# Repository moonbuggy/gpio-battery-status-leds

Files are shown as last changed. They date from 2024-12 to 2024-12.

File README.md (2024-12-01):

# GPIO Battery Status LEDs
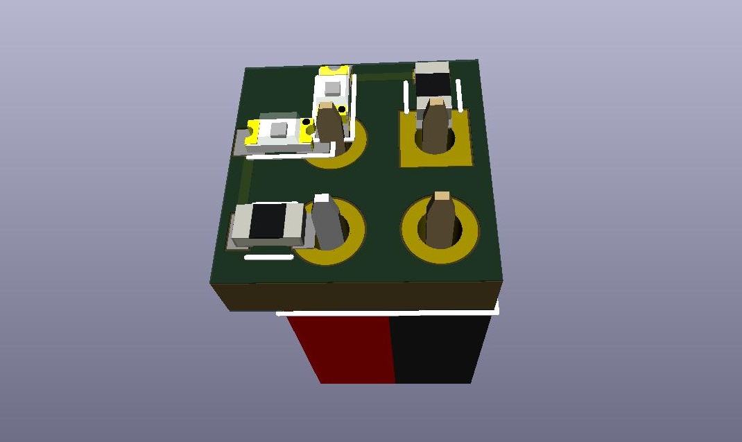
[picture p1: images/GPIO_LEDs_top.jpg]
3D-render


A little circuit board with red and green LEDs that plugs directly into a GPIO
header to indicate a status. The associated software reads a battery voltage
from an I2C/SMbus ADC and switches from the green to red LED when the voltage
falls below a certain threshold.

<!-- TOC depthFrom:2 depthTo:6 withLinks:1 updateOnSave:0 orderedList:0 -->

-   [Hardware](#hardware)
-   [Software](#software)
    -   [Installation](#installation)
    -   [Battery Monitor](#battery-monitor)
        -   [check_battery.py](#checkbatterypy)
        -   [robot-dog-battery-check.service](#robot-dog-battery-checkservice)
    -   [Robot Dog](#robot-dog)
        -   [robot-dog-server.service](#robot-dog-serverservice)
-   [Links](#links)

<!-- /TOC -->

The _battery_check.py_ script can be run standalone, but the _systemd_ service
files in this repository are aimed at a
[Freenove Robot Dog][Freenove Robot Dog Site] so they will need to be modified
if using the script in a different scenario.

The circuit board is usable as a general GPIO status indicator and it's not too
hard to modify these files, or create new files, to adapt for an arbitrary use.

## Hardware
It's just a couple of LEDs with current limiting resistors stuck on the end of
a 2x2 pin socket.

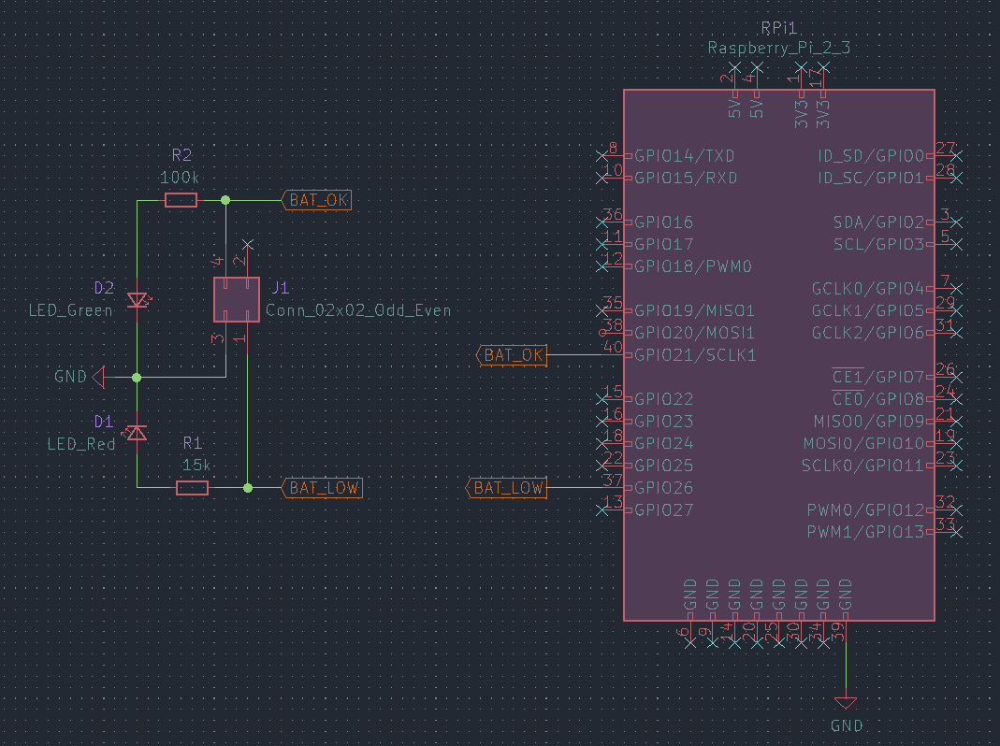
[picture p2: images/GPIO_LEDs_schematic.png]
GPIO LEDs schematic


One of the pin sockets is red, to aid alignment when attaching to the GPIO. It
fits nicely on pins 37-40 on a Raspberry Pi GPIO header, but will work anywhere
there's a pair of GPIO pins adjacent to a ground pin.

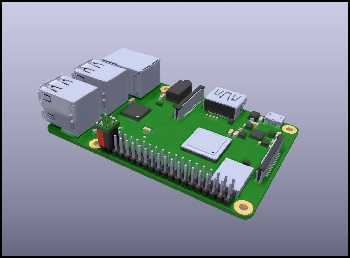
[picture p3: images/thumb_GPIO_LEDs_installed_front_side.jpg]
GPIO LEDs installed side view

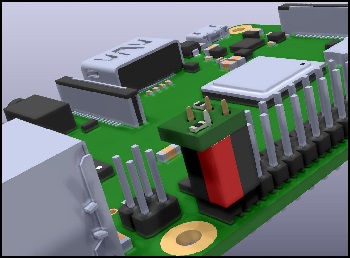
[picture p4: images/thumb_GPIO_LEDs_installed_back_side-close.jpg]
GPIO LEDs installed close view


## Software
### Installation
The _install.sh_ script is specific for the Freenvove Robot dog, installing
_systemd_ unit files for both the battery monitoring service and the server
software that allows control of the robot.

Usage:
```sh
sudo ./install.sh (<path_to_freenove_software>)
```

The directory the script is executed from will be used as the path for the
Freenove software if none is provided as an argument.

The _install.sh_ script can be used as a guide for manual installation, if the
application isn't a robot dog or some components aren't desired for whatever
reason.

### Battery Monitor
#### check_battery.py
The _check_battery.py_ script simply runs a loop, reading ADC data on a delay
(5 seconds by default) and comparing it against a threshold value, then toggles
the LEDs when the threshold is crossed. As is, the script will enable the green
LED when the battery voltage is above the threshold (i.e charged) and switch to
the red LED when the battery voltage is below the threshold (i.e. low capacity).

Usage:
```sh
./check_battery.py
```

By default the script looks for an ADS7830 ADC at address _0x48_ on _SMBus 1_.

Variables, including the specific GPIO pins to use and the addressing of the
ADC, are defined at the top of the script and are easily changed. A class for a
different ADC shouldn't be hard to add.

The units (volts) are only present in the log output and don't impact data
processing, so it's just a matter of changing some log message strings to
display the right units if monitoring something other than voltage.

#### robot-dog-battery-check.service
The _robot-dog-battery-check.service_ systemd unit file will start the battery
monitor, however it is configured for the Freenove robot dog and is thus tied
to the _robot-dog-server.service_. The unit file will work standalone if the
```BindsTo=``` and ```After=``` lines are removed.

Bound to the robot dog control server as it is, the _check_battery.py_ script
won't start until the control software is started and will stop if the control
software is stopped. This provides a third LED state, with both LEDs off being
an indication that the robot dog is not ready to be controlled.

### Robot Dog
#### robot-dog-server.service
The Freenove robot dog comes with instructions to start the server inside a GUI,
after the GUI is up. If we choose to start the control software in _systemd_,
instead of during the desktop GUI's initialisation, we have the option of
disabling the GUI entirely and saving some resources and maybe improving battery
life.

The _robot-dog-server.service_ needs to be modified to add the path to the
Freenove software, although this will be done automatically if using
_install.sh_ to install everything.

## Links
### Freenove Robot Dog
*   [Freenove][Freenove Robot Dog Site]
*   [Github][Freenove Robot Dog Github]

### Datasheets
*   [ADS7830](https://www.ti.com/lit/gpn/ADS7830)

[Freenove Robot Dog Site]: https://store.freenove.com/products/fnk0050
[Freenove Robot Dog Github]: https://github.com/Freenove/Freenove_Robot_Dog_Kit_for_Raspberry_Pi

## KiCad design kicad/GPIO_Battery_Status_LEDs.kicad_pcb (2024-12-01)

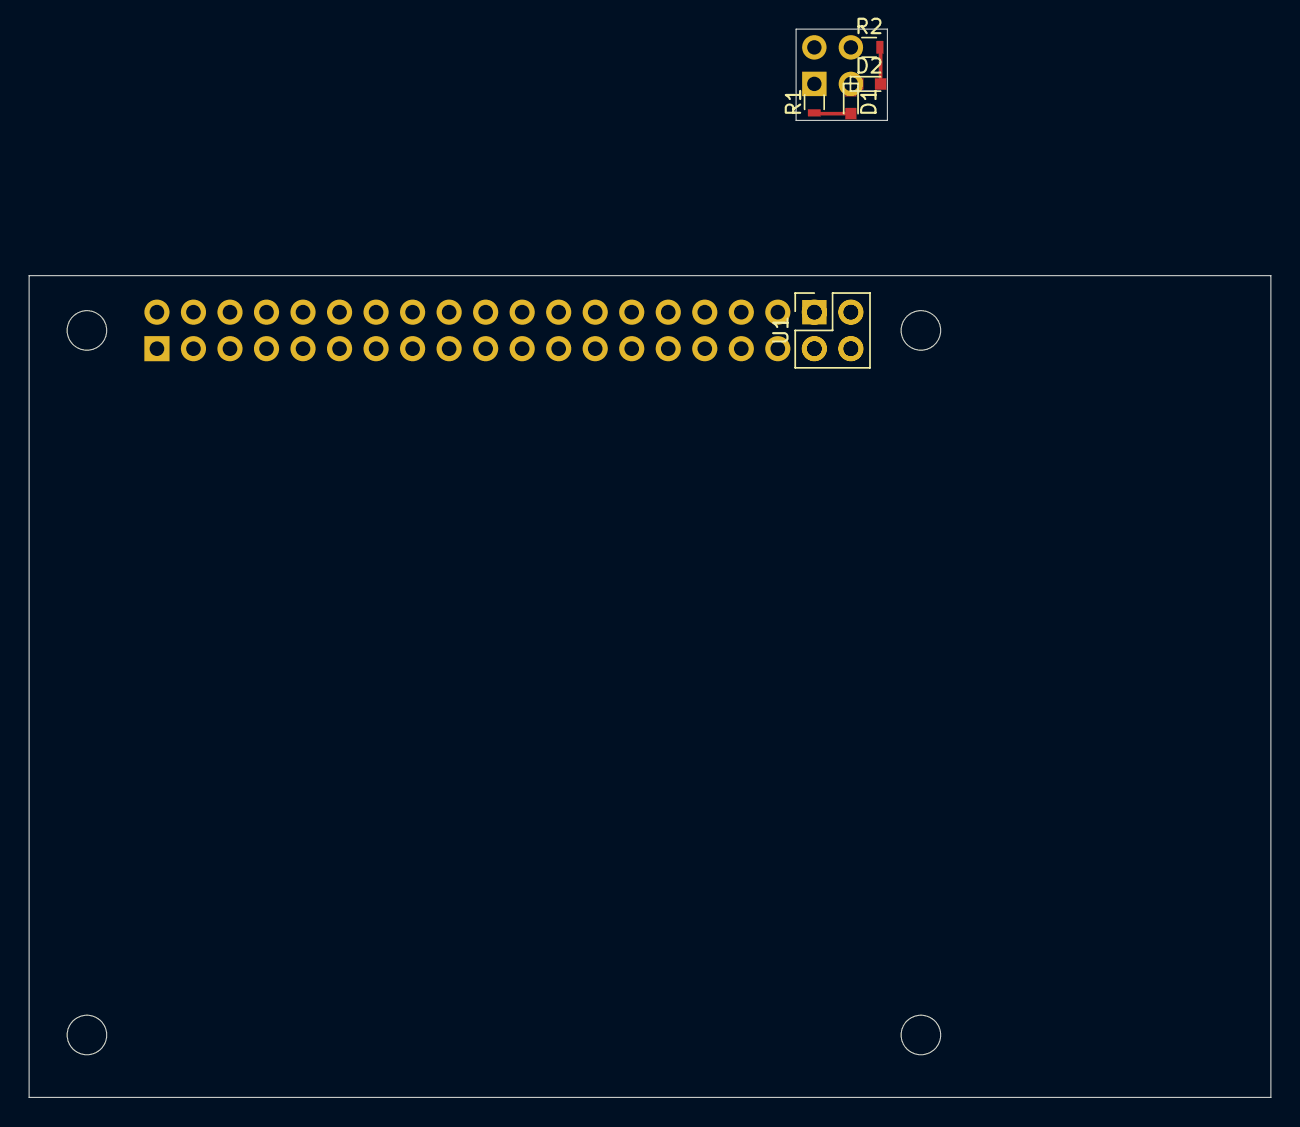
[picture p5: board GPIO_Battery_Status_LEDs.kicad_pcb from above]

Board: 2 copper layers, 86.4 x 74.3 mm, 7 parts (1 on the bottom side), 5 nets.

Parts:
D1: LED_Red; LED_0603
D2: LED_Green; LED_0603
J1: Conn_02x02_Odd_Even; Socket_Strip_Straight_2x02_Pitch2.54mm-1-red
R1: 15k; R_0603
R2: 100k; R_0603
RPi1: Raspberry_Pi_2_3; raspberrypi_2_3
U1: GPIO_Status_LEDs

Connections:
BAT_LOW: J1.1, R1.2, RPi1.37, U1.2
BAT_OK: J1.4, R2.1, RPi1.40, U1.3
GND: D1.1, D2.1, J1.3, RPi1.39, U1.4
unnamed: D1.2, R1.1
unnamed: D2.2, R2.2

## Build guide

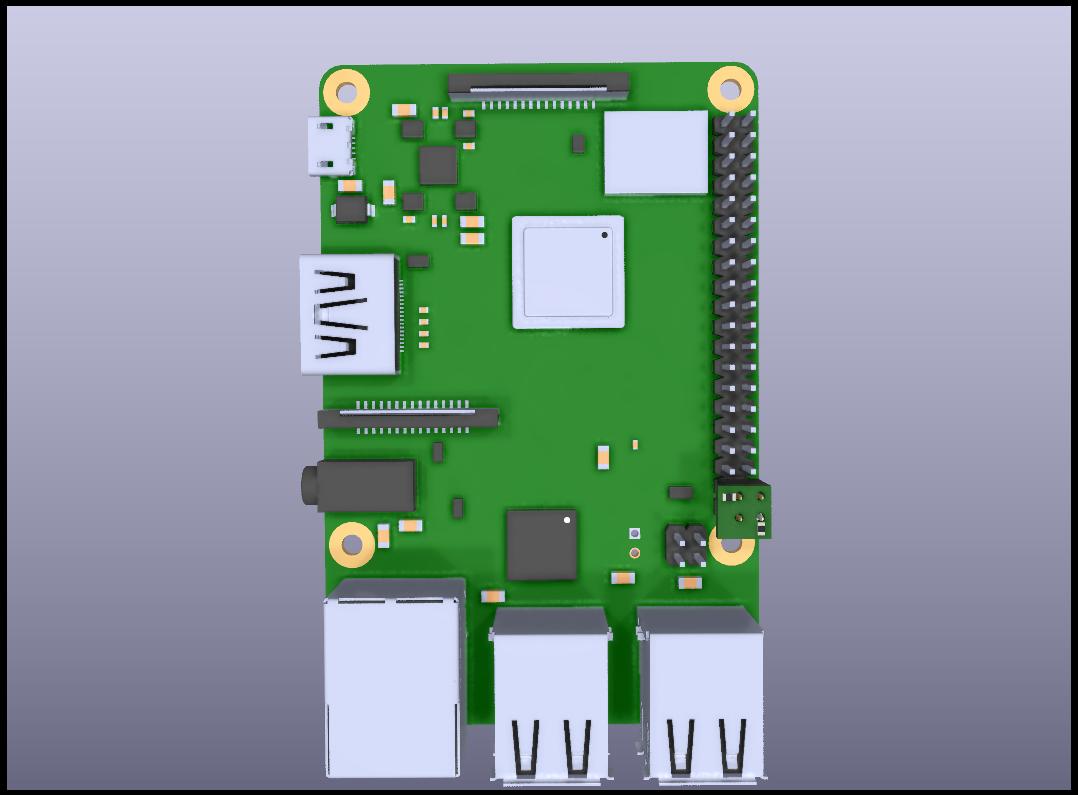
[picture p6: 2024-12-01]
images/GPIO_LEDs_installed_top.jpg

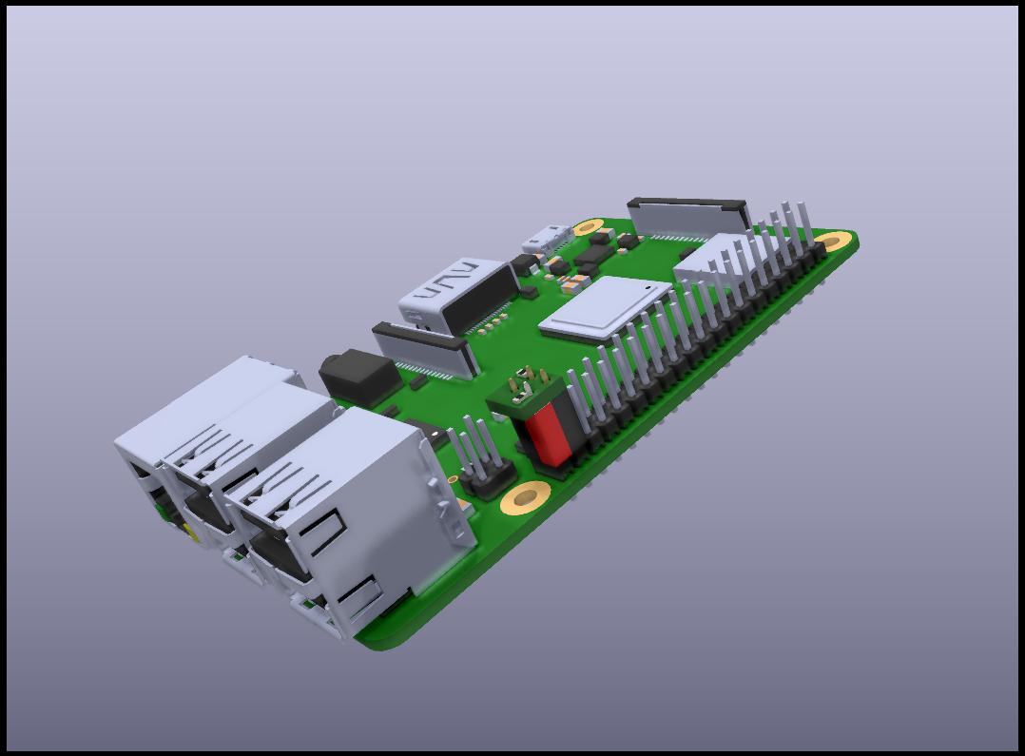
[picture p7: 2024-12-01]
images/GPIO_LEDs_installed_back_side.jpg

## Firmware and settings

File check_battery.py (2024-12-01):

#!/usr/bin/env python3
"""
SMBus Battery Status LEDs.

Monitor a battery voltage via an ADC and switch status LEDs accordingly.
"""

import os
import sys
import time
import signal
import logging
import traceback
import atexit
import gpio  # type: ignore
import smbus3 as smbus
import sdnotify  # type: ignore

CHECK_INTERVAL = 5

# it's 3.2V per cell in Server.py, and we want to switch to red before it
# shuts down, but we'll need to tune the number to give an appropriate warning
# time
LOW_VOLTAGE = 3.3

LED_PIN_GREEN = 21
LED_PIN_RED = 26

DEFAULT_LOG_LEVEL = logging.INFO

STDOUT_HANDLER = logging.StreamHandler(sys.stdout)
STDOUT_HANDLER.setFormatter(logging.Formatter(
                            '%(name)s - %(levelname)s - %(message)s'))

logger = logging.getLogger(os.path.splitext(os.path.basename(__file__))[0])
logger.addHandler(STDOUT_HANDLER)
logger.setLevel(DEFAULT_LOG_LEVEL)


def signal_handler(sig, _frame):  # pylint: disable=unused-argument
    """Handle SIGINT cleanly."""
    logger.info('Caught signal %s, exiting..', sig)
    sys.exit(0)


signal.signal(signal.SIGINT, signal_handler)
signal.signal(signal.SIGTERM, signal_handler)

notifier = sdnotify.SystemdNotifier()


class ADS7830:  # pylint: disable=invalid-name
    """
    An ADS730 ADC on the SMBus.

    Read the ADC via the SMBus and convert the data to a voltage for the
    battery it's monitoring.
    """

    def __init__(self, channel=0):
        """Get the bus, set address and command."""
        self.bus = smbus.SMBus(1)
        self.ADC_ADDRESS = 0x48
        self.ADC_COMMAND = 0x84  # Single-Ended Inputs
        self.channel = channel

        # convert ADC data to voltage
        #
        # NOTE: Dog's PDF say's it's multilpied by 3, example code says it's
        #       multiplied by 2. This number should match the number of
        #       battery cells, so 2 is correct for the Freenove Robot Dog.
        self.ADC_SCALE = 1 / 255.0 * 5.0 * 2

    def read_adc(self):
        """Read the ADC as defined by __init__."""
        command_set = self.ADC_COMMAND | \
            ((((self.channel << 2) | (self.channel >> 1)) & 0x07) << 4)
        self.bus.write_byte(self.ADC_ADDRESS, command_set)
        data = self.bus.read_byte(self.ADC_ADDRESS)
        return data

    def get_data(self):
        """Convert the raw ADC data into an integer."""
        data = ['', '', '', '', '', '', '', '', '']
        for i in range(9):
            data[i] = self.read_adc()
        data.sort()
        return data[4]

    def voltage(self, data=None):
        """
        Convert ADC data into a voltage based on the calibration.

        If not data is provided, fetch it from get_data().
        """
        if not data:
            data = self.get_data()
        return data * self.ADC_SCALE


class StatusIndicator:
    """Indicate the status of the battery via LEDs attached tot he GPIO.."""

    def __init__(self, adc):
        """Set pin numbers for LEDs."""
        try:
            self.pin_green = gpio.GPIOPin(LED_PIN_GREEN, gpio.OUT)
            self.pin_red = gpio.GPIOPin(LED_PIN_RED, gpio.OUT)
        except PermissionError:
            logger.error('No write permission to /sys/class/gpio/export.')
            sys.exit(1)

        self.adc = adc
        self.low_volt = LOW_VOLTAGE
        self.status_text = ['LOW', 'OKAY']

        # it's less maths overall if we convert the low voltage limit into the
        # same scale as the raw ADC data, then we only have to do the maths
        # once during init
        self.low_volt_cutoff = self.low_volt / adc.ADC_SCALE

        self.last_bat_status = None

        logger.info('Initialization done. Signalling readiness.')
        notifier.notify('READY=1')

    def check(self):
        """Check the voltage and determine if status has changed."""
        data = self.adc.read_adc()
        this_bat_status = bool(data > self.low_volt_cutoff)

        if this_bat_status != self.last_bat_status:
            self.set_status(this_bat_status)
        self.last_bat_status = this_bat_status

        # return the scaled voltage
        return self.adc.voltage(data)

    def set_status(self, this_status=False):
        """
        Switch the LEDs based on the status.

        When status is 'true', indicate 'okay'. Otherwise, indicate 'low'.
        """
        if this_status:
            self.pin_green.write(gpio.HIGH)
            self.pin_red.write(gpio.LOW)
        else:
            self.pin_green.write(gpio.LOW)
            self.pin_red.write(gpio.HIGH)

        # including the voltage here is extra maths every run, defeats the point
        # of being efficient by doing the comparison on the un-scaled data in
        # check()
        logger.info('Battery status changed to %s (%sV)',
                    self.status_text[this_status], str(self.adc.voltage())[:5])

    def disable(self):
        """Switch both LEDs off."""
        logger.info("Disabling both status LEDs.")
        self.pin_green.write(gpio.LOW)
        self.pin_red.write(gpio.LOW)


def main():
    """Do all the things."""
    adc = ADS7830()
    bat_status = StatusIndicator(adc)
    atexit.register(bat_status.disable)

    while True:
        try:
            volts = bat_status.check()
            notifier.notify(f'STATUS=Battery voltage: {volts:.3f}V')
        except Exception:  # pylint: disable=broad-exception-caught
            logger.error(traceback.format_exc())
            sys.exit(1)

        time.sleep(CHECK_INTERVAL)


if __name__ == '__main__':
    main()
